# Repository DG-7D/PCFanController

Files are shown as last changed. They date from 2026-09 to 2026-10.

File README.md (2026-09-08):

- 操作
    - PA5: +入力 / ロータリエンコーダA相入力
    - PA6: -入力 / ロータリエンコーダB相入力
    - PA7: 決定入力
- 7セグ
    - PA1: データ出力
    - PA3: クロック出力
    - PA4: ラッチ出力
- ファン
    - PB1: 回転数パルス入力
    - PB0: PWM出力
- その他
    - PA0: RESET / UPDI
    - PA2: MISO (未使用)

```
ATtiny404

   VDD GND
7R PA4 PA3 7C
i  PA5 PA2 x
i  PA6 PA1 7D
i  PA7 PA0 x
   PB3 PB0 FP
   PB2 PB1 FT
```

```
74HC595
QB  VCC
QC   QA
QD   SI 7D
QE    G GND
QF  RCK 7R
QG  SCK 7C
QH  SCL VCC
GND QH'
```

```
pio run -t fuses
pio run -t upload
```

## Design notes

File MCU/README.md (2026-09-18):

- 操作
    - PA7: 表示ボタン
    - PA6: +ボタン
    - PA5: -ボタン
- 7セグ
    - PA1: データ出力
    - PA3: クロック出力
    - PA4: ラッチ出力
    - PB3: 有効出力 (Active Low)
- ファン
    - PB0: 回転数パルス入力
    - PB1: PWM出力
- その他
    - PA0: RESET / UPDI
    - PA2: MISO (未使用)
    - PB2: TxD

```
ATtiny404

   VDD GND
7R PA4 PA3 7C
i- PA5 PA2 x
i+ PA6 PA1 7D
iD PA7 PA0 UPDI
7E PB3 PB0 FT
Tx PB2 PB1 FP
```

```
74HC595

A QB  VCC
F QC   QA B
E QD   SI 7D
D QE    G GND
P QF  RCK 7R
C QG  SCK 7C
G QH  SCL VCC
  GND QH'

x QB  VCC
x QC   QA x
x QD   SI 7D
3 QE    G GND
2 QF  RCK 7R
1 QG  SCK 7C
0 QH  SCL VCC
  GND QH'
```

```
pio run -t fuses
pio run -t upload
```

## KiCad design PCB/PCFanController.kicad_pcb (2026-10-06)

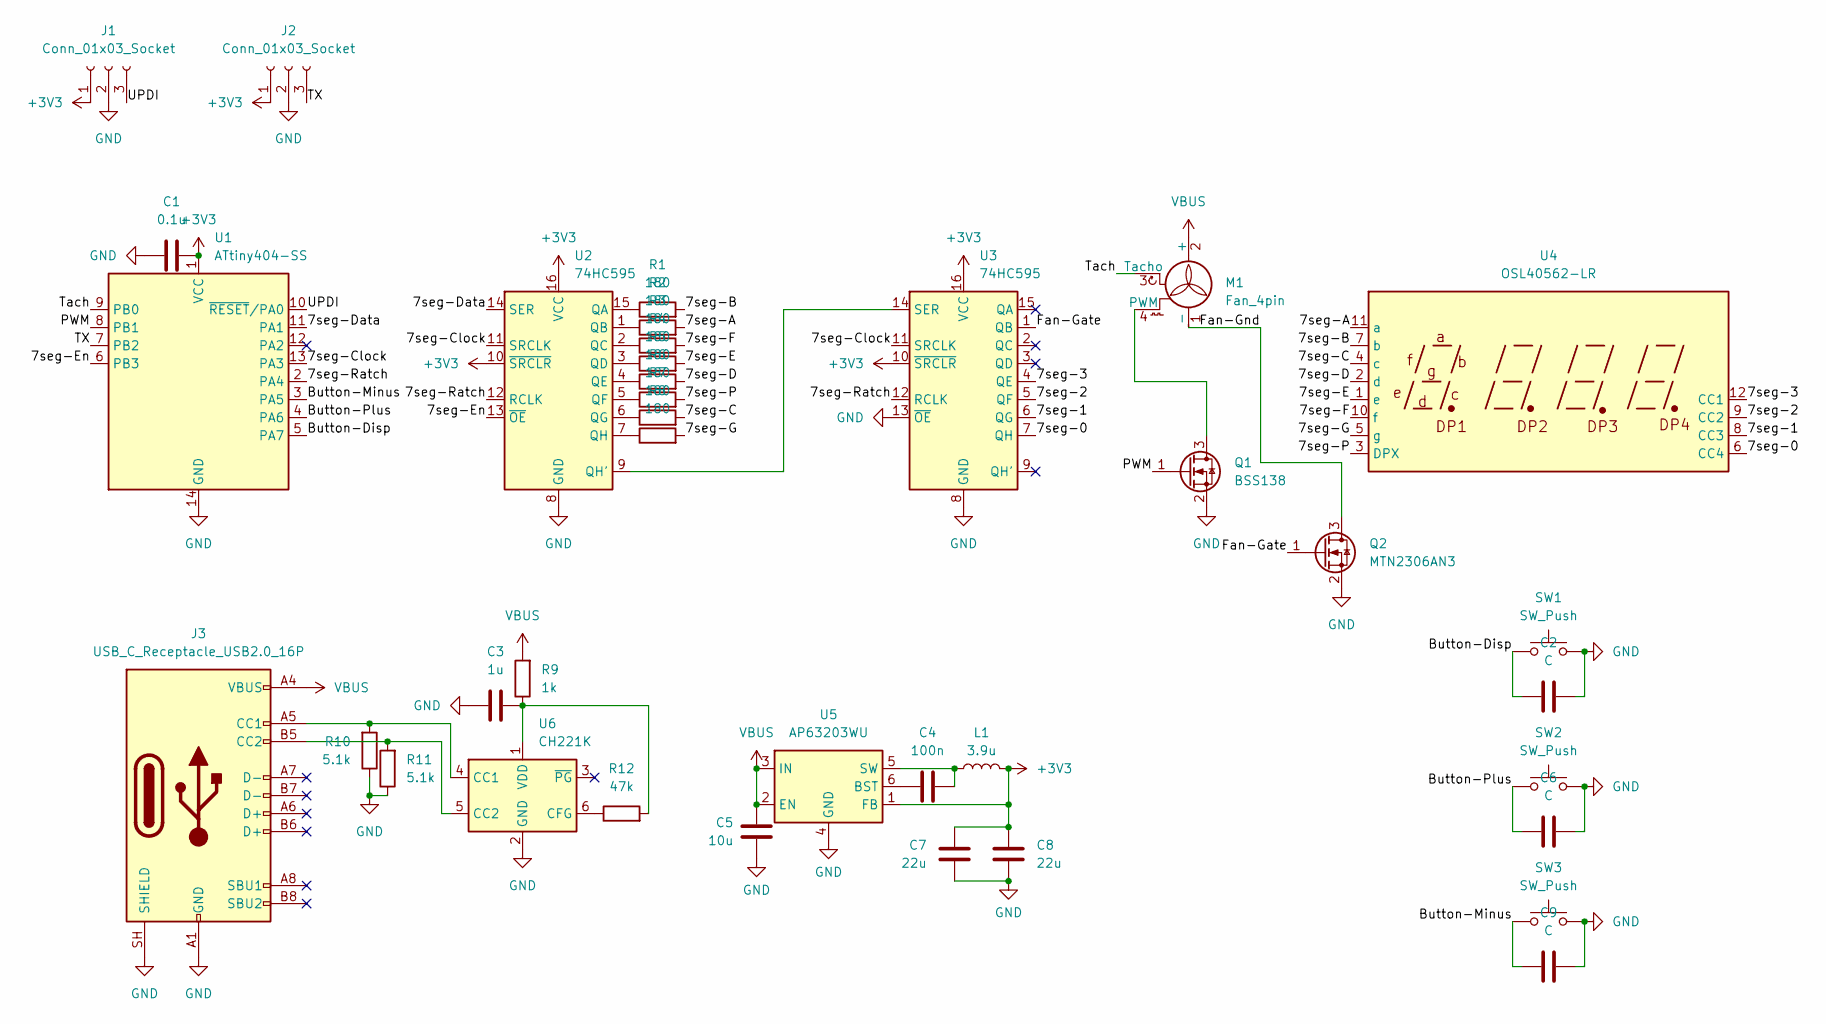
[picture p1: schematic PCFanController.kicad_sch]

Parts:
C1: 0.1u; C_0603_1608Metric
C2, C6, C9: C; C_0603_1608Metric
C3: 1u; C_0603_1608Metric
C4: 100n; C_0603_1608Metric
C5: 10u; C_0603_1608Metric
C7, C8: 22u; C_0603_1608Metric
J1, J2: Conn_01x03_Socket; PinSocket_1x03_P2.54mm_Vertical
J3: USB_C_Receptacle_USB2.0_16P; USB_C_Receptacle_GCT_USB4105-xx-A_16P_TopMnt_Horizontal
L1: 3.9u; L_1210_3225Metric
M1: Fan_4pin; FanPinHeader_1x04_P2.54mm_Vertical
Q1: BSS138; SOT-23
Q2: MTN2306AN3; SOT-23
R1, R2, R3, R4, R5, R6, R7, R8: 180; R_0603_1608Metric
R9: 1k; R_0603_1608Metric
R10, R11: 5.1k; R_0603_1608Metric
R12: 47k; R_0603_1608Metric
SW1, SW2, SW3: SW_Push; R_Axial_DIN0204_L3.6mm_D1.6mm_P5.08mm_Horizontal
U1: ATtiny404-SS; SOIC-14_3.9x8.7mm_P1.27mm
U2, U3: 74HC595; TSSOP-16_4.4x5mm_P0.65mm
U4: OSL40562-LR; CA56-12EWA
U5: AP63203WU; TSOT-23-6
U6: CH221K; SOT-23-6

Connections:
+3V3: C1.2, C7.2, C8.2, J1.1, J2.1, L1.2, U1.1 (VCC), U2.10 (~SRCLR), U2.16 (VCC), U3.10 (~SRCLR), U3.16 (VCC), U5.1 (FB)
/7seg-0: U3.7 (QH), U4.6 (CC4)
/7seg-1: U3.6 (QG), U4.8 (CC3)
/7seg-2: U3.5 (QF), U4.9 (CC2)
/7seg-3: U3.4 (QE), U4.12 (CC1)
/7seg-A: R2.2, U4.11 (a)
/7seg-B: R1.2, U4.7 (b)
/7seg-C: R7.2, U4.4 (c)
/7seg-Clock: U1.13 (PA3), U2.11 (SRCLK), U3.11 (SRCLK)
/7seg-D: R5.2, U4.2 (d)
/7seg-Data: U1.11 (PA1), U2.14 (SER)
/7seg-E: R4.2, U4.1 (e)
/7seg-En: U1.6 (PB3), U2.13 (~OE)
/7seg-F: R3.2, U4.10 (f)
/7seg-G: R8.2, U4.5 (g)
/7seg-P: R6.2, U4.3 (DPX)
/7seg-Ratch: U1.2 (PA4), U2.12 (RCLK), U3.12 (RCLK)
/Button-Disp: C2.1, SW1.1, U1.5 (PA7)
/Button-Minus: C9.1, SW3.1, U1.3 (PA5)
/Button-Plus: C6.1, SW2.1, U1.4 (PA6)
/Fan-Gate: Q2.1 (G), U3.1 (QB)
/Fan-Gnd: M1.1 (-), Q2.3 (D)
/PWM: Q1.1 (G), U1.8 (PB1)
/TX: J2.3, U1.7 (PB2)
/Tach: M1.3 (Tacho), U1.9 (PB0)
/UPDI: J1.3, U1.10 (~RESET/PA0)
GND: C1.1, C2.2, C3.1, C5.2, C6.2, C7.1, C8.1, C9.2, J1.2, J2.2, J3.A1 (GND), J3.A12 (GND), J3.B1 (GND), J3.B12 (GND), J3.SH (SHIELD), Q1.2 (S), Q2.2 (S), R10.1, R11.1, SW1.2, SW2.2, SW3.2, U1.14 (GND), U2.8 (GND), U3.8 (GND), U3.13 (~OE), U5.4 (GND), U6.2 (GND)
unnamed: J3.A5 (CC1), R10.2, U6.4 (CC1)
unnamed: J3.B5 (CC2), R11.2, U6.5 (CC2)
unnamed: M1.4 (PWM), Q1.3 (D)
unnamed: R1.1, U2.15 (QA)
unnamed: R2.1, U2.1 (QB)
unnamed: R3.1, U2.2 (QC)
unnamed: R4.1, U2.3 (QD)
unnamed: R5.1, U2.4 (QE)
unnamed: R6.1, U2.5 (QF)
unnamed: R7.1, U2.6 (QG)
unnamed: U2.9 (QH'), U3.14 (SER)
unnamed: R8.1, U2.7 (QH)
unnamed: C4.1, U5.6 (BST)
unnamed: C4.2, L1.1, U5.5 (SW)
unnamed: R12.1, U6.6 (CFG)
unnamed: C3.2, R9.1, R12.2, U6.1 (VDD)
VBUS: C5.1, J3.A4 (VBUS), J3.A9 (VBUS), J3.B4 (VBUS), J3.B9 (VBUS), M1.2 (+), R9.2, U5.2 (EN), U5.3 (IN)

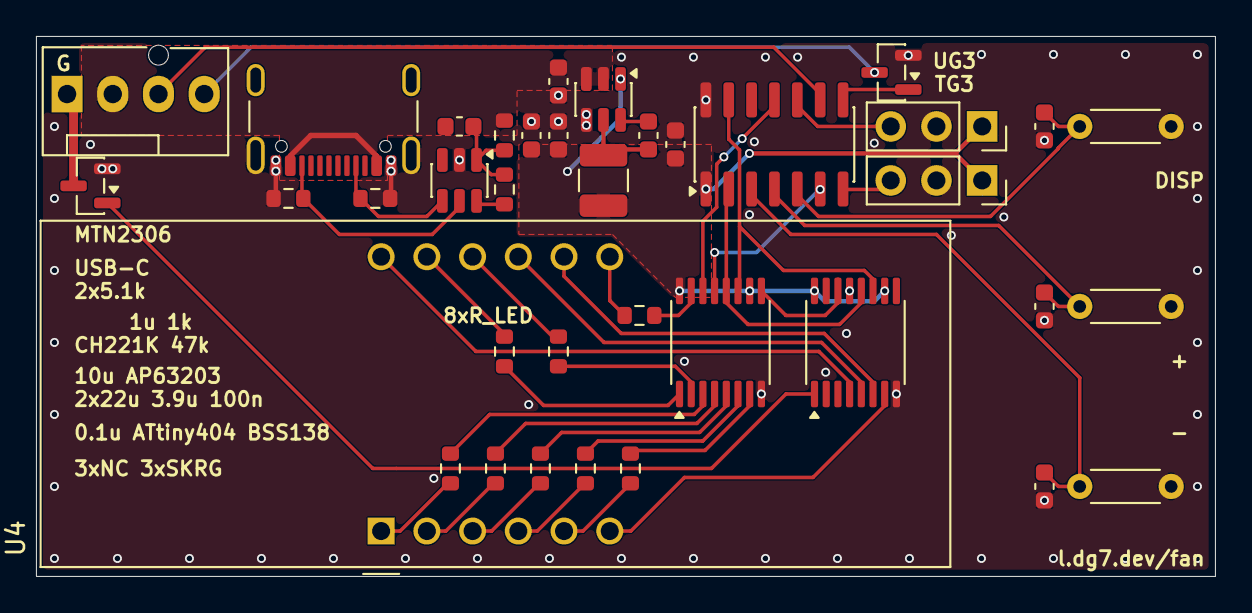
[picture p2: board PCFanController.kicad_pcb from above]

Board: 2 copper layers, 65.5 x 30.0 mm, 37 parts (0 on the bottom side), 44 nets.

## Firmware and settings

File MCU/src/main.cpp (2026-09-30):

#include <avr/interrupt.h>
#include <avr/io.h>

constexpr uint8_t POWER_STEP = 10;
constexpr uint16_t MIN_RPM = 120;
constexpr float LED_BRIGHTNESS = 0.5;

constexpr uint32_t PWM_FREQ = 25000;           // ticks/s
constexpr uint8_t LED_TICKS_PER_DIGIT = 64;    // 1桁391Hz、4桁98Hz
constexpr uint8_t BUTTON_DEBOUNCE_TICKS = 250; // てきとー 0.01s

constexpr uint16_t PWM_PERIOD_CLOCKS = F_CPU / PWM_FREQ;
constexpr uint16_t LED_ENABLE_CLOCKS = PWM_PERIOD_CLOCKS * (1 - LED_BRIGHTNESS);
constexpr uint32_t CLK_TICKS_PER_MIN = F_CPU / PWM_PERIOD_CLOCKS * 60;
constexpr uint32_t TIMEOUT_TICKS = CLK_TICKS_PER_MIN / MIN_RPM / 2;
constexpr uint16_t POW10[] = {1, 10, 100, 1000};

enum DISP : uint8_t {
    DISP_OFF,
    DISP_RPM,
    DISP_POWER,
    DISP_COUNT,
};

volatile uint16_t pulseWidth = 0;
volatile bool ledUpdateFlag = true;
volatile uint8_t power = 0;
volatile bool fanEnabled = false;
volatile DISP disp = DISP_RPM;
volatile uint8_t dispCharBuffer[4] = {};

int main() {
    _PROTECTED_WRITE(CLKCTRL.MCLKCTRLB, ~CLKCTRL_PEN_bm);

    PORTA.DIRSET = PIN1_bm | PIN3_bm | PIN4_bm;
    PORTA.DIRCLR = PIN5_bm | PIN6_bm | PIN7_bm;
    PORTA.PIN5CTRL = PORT_PULLUPEN_bm | PORT_ISC_FALLING_gc;
    PORTA.PIN6CTRL = PORT_PULLUPEN_bm | PORT_ISC_FALLING_gc;
    PORTA.PIN7CTRL = PORT_PULLUPEN_bm | PORT_ISC_FALLING_gc;

    PORTB.DIRSET = PIN1_bm | PIN2_bm | PIN3_bm;
    PORTB.DIRCLR = PIN0_bm;
    PORTB.PIN0CTRL = PORT_PULLUPEN_bm | PORT_ISC_RISING_gc;

    PORTMUX.CTRLC = PORTMUX_TCA00_ALTERNATE_gc;
    TCA0.SINGLE.CMP0 = LED_ENABLE_CLOCKS;
    TCA0.SINGLE.CMP1 = PWM_PERIOD_CLOCKS;
    TCA0.SINGLE.PER = PWM_PERIOD_CLOCKS - 1;
    TCA0.SINGLE.INTCTRL = TCA_SINGLE_OVF_bm;
    TCA0.SINGLE.CTRLB = TCA_SINGLE_CMP0EN_bm | TCA_SINGLE_CMP1EN_bm | TCA_SINGLE_WGMODE_SINGLESLOPE_gc;
    TCA0.SINGLE.CTRLA = TCA_SINGLE_CLKSEL_DIV1_gc | TCA_SINGLE_ENABLE_bm;

    SPI0.CTRLB = ~SPI_BUFEN_bm | SPI_SSD_bm | SPI_MODE_0_gc;
    SPI0.CTRLA = SPI_DORD_bm | SPI_MASTER_bm | ~SPI_CLK2X_bm | SPI_PRESC_DIV16_gc | SPI_ENABLE_bm;

    USART0.BAUD = 64 * F_CPU / 16 / 9600;
    USART0.CTRLC = USART_CMODE_ASYNCHRONOUS_gc | USART_PMODE_DISABLED_gc | USART_CHSIZE_8BIT_gc;
    USART0.CTRLB = USART_TXEN_bm | USART_RXMODE_NORMAL_gc;

    sei();

    uint16_t rpm = 0;
    uint8_t digit = 0;
    while (1) {
        if (disp == DISP_OFF) {
            TCA0.SINGLE.CMP0 = PWM_PERIOD_CLOCKS;
            continue;
        } else {
            TCA0.SINGLE.CMP0 = LED_ENABLE_CLOCKS;
        }
        TCA0.SINGLE.CMP1 = PWM_PERIOD_CLOCKS * (100 - power) / 100;

        if (ledUpdateFlag) {
            ledUpdateFlag = false;

            set595(fanEnabled, digit, dispCharBuffer[digit]);
            digit = (digit + 1) % 4;

            if (digit == 0) {
                sendUART(dispCharBuffer[3]);
                sendUART(dispCharBuffer[2]);
                sendUART(dispCharBuffer[1]);
                sendUART(dispCharBuffer[0]);
                sendUART('\n');

                if (fanEnabled) {
                    switch (disp) {
                    case DISP_RPM:
                        cli();
                        const uint16_t ticks = pulseWidth;
                        sei();
                        if (ticks == 0) {
                            rpm = 0;
                        } else {
                            rpm = CLK_TICKS_PER_MIN / ticks / 2;
                        }
                        for (uint8_t i = 0; i < 4; i++) {
                            dispCharBuffer[i] = '0' + (rpm / POW10[i] % 10);
                        }
                        break;

                    case DISP_POWER:
                        dispCharBuffer[3] = ' ';
                        for (uint8_t i = 0; i < 3; i++) {
                            dispCharBuffer[i] = '0' + (power / POW10[i] % 10);
                        }
                        break;
                    }
                } else {
                    dispCharBuffer[3] = ' ';
                    dispCharBuffer[2] = 'O';
                    dispCharBuffer[1] = 'F';
                    dispCharBuffer[0] = 'F';
                }
            }
        }
    }
}

volatile uint16_t tick = 0;
volatile uint16_t lastPulseTick = 0;
volatile uint8_t buttonDebounceTicks = 0;
volatile uint8_t lastButtonState = 0;

ISR(PORTA_PORT_vect) {
    PORTA.INTFLAGS = PIN5_bm | PIN6_bm | PIN7_bm;
    lastButtonState = PORTA.IN & (PIN5_bm | PIN6_bm | PIN7_bm);
    buttonDebounceTicks = BUTTON_DEBOUNCE_TICKS;
}

ISR(PORTB_PORT_vect) {
    PORTB.INTFLAGS = PIN0_bm;
    const uint16_t now = tick;
    pulseWidth = now - lastPulseTick;
    lastPulseTick = now;
}

ISR(TCA0_OVF_vect) {
    TCA0.SINGLE.INTFLAGS = TCA_SINGLE_OVF_bm;
    tick++;
    if (tick % LED_TICKS_PER_DIGIT == 0) {
        ledUpdateFlag = true;
    }
    if (tick == lastPulseTick + TIMEOUT_TICKS) {
        pulseWidth = 0;
    }
    if (buttonDebounceTicks > 0) {
        buttonDebounceTicks--;

        if (buttonDebounceTicks == 0 && (PORTA.IN & (PIN5_bm | PIN6_bm | PIN7_bm)) == lastButtonState) {
            if (!(lastButtonState & PIN5_bm)) {
                if (!fanEnabled) {
                    fanEnabled = true;
                    return;
                }
                if (power <= 100 - POWER_STEP) {
                    power = power + POWER_STEP;
                } else {
                    power = 100;
                }
            } else if (!(lastButtonState & PIN6_bm)) {
                if (power == 0) {
                    fanEnabled = false;
                    return;
                }
                if (POWER_STEP <= power) {
                    power = power - POWER_STEP;
                } else {
                    power = 0;
                }
            } else if (!(lastButtonState & PIN7_bm)) {
                if (disp != DISP_COUNT - 1) {
                    disp = (DISP)(disp + 1);
                } else {
                    disp = DISP_OFF;
                }
            }
        }
    }
}

static inline void sendSPI(uint8_t data) {
    SPI0.DATA = data;
    while (!(SPI0.INTFLAGS & SPI_IF_bm)) {
        ;
    }
}

static inline void sendUART(uint8_t data) {
    while (!(USART0.STATUS & USART_DREIF_bm)) {
        ;
    }
    USART0.TXDATAL = data;
}

static inline void set595(bool fanEnable, uint8_t digit, uint8_t character) {
    PORTA.OUTCLR = PIN4_bm;
    sendSPI(1 << digit | (fanEnable ? 0 : FAN_SW_BIT));
    sendSPI(LED_7SEG_CHAR_BITS[character]);
    PORTA.OUTSET = PIN4_bm;
}
constexpr const uint8_t LED_7SEG_CHAR_BITS[] = {
    //        GCPDEFAB
    ['0'] = 0b01011111,
    ['1'] = 0b01000001,
    ['2'] = 0b10011011,
    ['3'] = 0b01011011,
    ['4'] = 0b11000101,
    ['5'] = 0b11010110,
    ['6'] = 0b11011101,
    ['7'] = 0b01000011,
    ['8'] = 0b11011111,
    ['9'] = 0b11011011,
    //        GCPDEFAB
    [' '] = 0b00000000,
    ['O'] = 0b01011111,
    ['F'] = 0b10001110,
};
constexpr uint8_t LED_7SEG_DP_BIT = 0b00100000;
constexpr uint8_t FAN_SW_BIT = 0b01000000; // Lowで駆動

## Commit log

2026-09-07 とりあえず回転数が取れる
2026-09-07 多分シフトレジスタ殴れる
2026-09-07 表示しないもの計算する必要ないよね
2026-09-08 LSBFirst QAが変な場所にあるので
2026-09-08 PCB WIP
    [PCFanController.kicad_pcb, PCFanController.kicad_sch]
2026-09-13 シリアル出力
2026-09-15 テストポイントとか
    [PCFanController.kicad_sch]
2026-09-15 PWMとTachを入れ替え
    TCAのWO0をRX(多分使わない)に回せるように
2026-09-15 OEのPWM
    [PCFanController.kicad_sch]
2026-09-15 READMEのピン配置修正
2026-09-15 パルス幅可変
2026-09-15 チャタリング回避 あんま効かない
2026-09-18 なんかいい感じになった?
2026-09-18 ピンアサイン変更、PCB
    [PCFanController.kicad_pcb, PCFanController.kicad_sch]
2026-09-28 テストポイントをスルーホールに変更
    [PCFanController.kicad_pcb, PCFanController.kicad_sch]
2026-09-28 抵抗値修正
    [PCFanController.kicad_pcb, PCFanController.kicad_sch]
2026-09-28 ベタはがした、MOSFET貼った
    [PCFanController.kicad_pcb, PCFanController.kicad_sch]
2026-09-28 配線修正
    [PCFanController.kicad_pcb]
2026-09-28 とりあえずボタン押すまで待機?
2026-09-28 これでいいじゃんね
2026-09-30 文字でバッファ持つ?
2026-09-30 ISR中でなくていいものをmainループに
2026-09-30 場所整理
2026-09-30 表示と停止をいろいろ
2026-09-30 逆だよね
2026-10-01 VBus表に、桁選択からENを外し
    [PCFanController.kicad_pcb, PCFanController.kicad_sch]
2026-10-01 配線整理、ベタ塗った
    [PCFanController.kicad_pcb]
2026-10-06 抵抗値変更
    [PCFanController.kicad_pcb, PCFanController.kicad_sch]
2026-10-13 未実装を明示
2026-10-14 テスト穴のシルク撤去
2026-10-21 ファンのピンアサイン
2026-10-29 怒られを修正
2026-10-29 謝られを修正
2026-10-30 ボタンが+-逆なのを修正
2026-10-30 Nch MOSFETはHIGHで導通ですよ???
2026-10-30 これでcase DISP_POWERに入るようになるらしい???
2026-10-30 LEDのピン修正
2026-10-31 ヒステリシス RPM単位だと微妙かも?
2026-10-31 tick単位のフィルタ
2026-10-31 非表示中でも操作できるようにした、非表示から切り替えたとき残骸が表示されないようにした
